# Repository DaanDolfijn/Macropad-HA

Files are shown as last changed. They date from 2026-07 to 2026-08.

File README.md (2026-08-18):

# Macropad-HA
<h2>A macropad that controls home assistant using espHome.</h2>
<p>This is NOT a Hackpad</p> 

<br>

<br>
<a href="https://youtu.be/JzanmzNsBhA"> See working here</a>
<h2>Features</h2>
<p>
  1. 4x4 buttons that are programmable in HA. <br>
  2. An 128X64 oled screen that displays time and whats playing on spotify using a HA spotify intergration. <br>
  3. 2 rgb leds that are programmable in HA. <br>
  4. 2 potentiometers that are programmable in HA</p>

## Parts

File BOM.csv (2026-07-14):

Item | Qty Needed | Qty Owned | Price ($)
Potentimetor | 2 | 2 | 3
RGB leds | 2 | 2 | 0.60
Oled screen 128x64 | 1 | 1 | 2
ESP32 s3 | 1 | 1 | 8
Keyboard switch | 16 | 16 | 3
Keycap | 16 | 16 | 5
PCB | 1 | 0 | 25

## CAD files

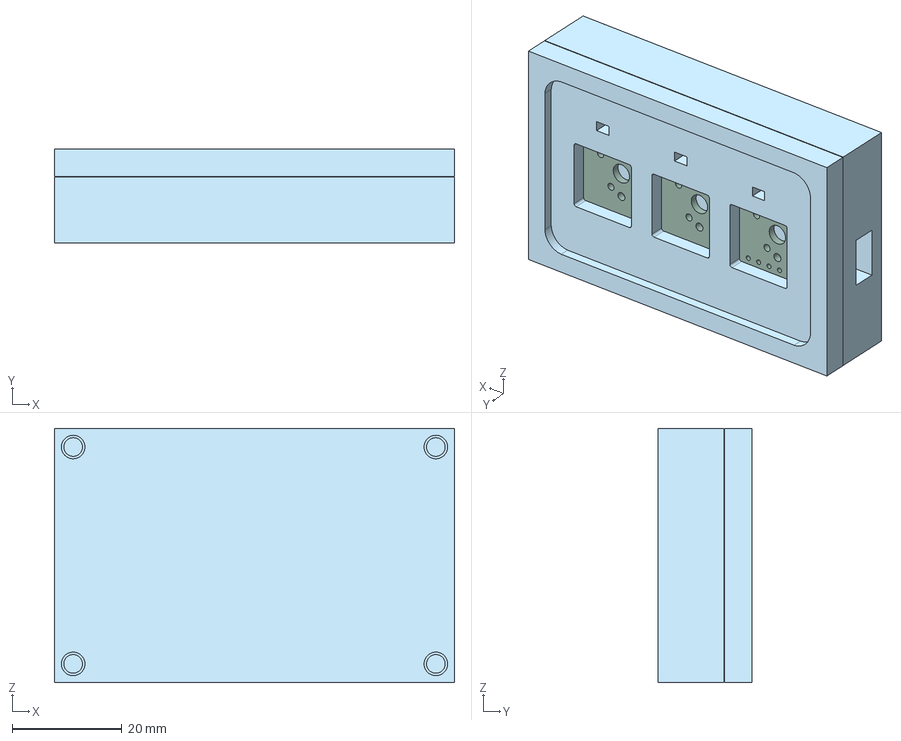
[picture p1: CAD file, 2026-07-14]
Assembly.step
73.0 x 17.1 x 46.4 mm
yo_PCB

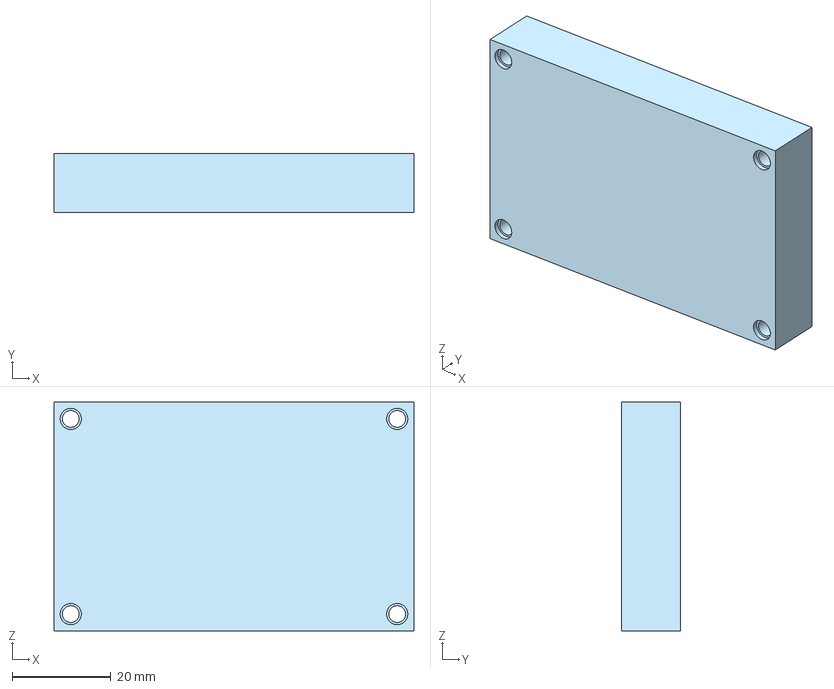
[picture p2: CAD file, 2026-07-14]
Bottom.step
73.0 x 12.0 x 46.4 mm

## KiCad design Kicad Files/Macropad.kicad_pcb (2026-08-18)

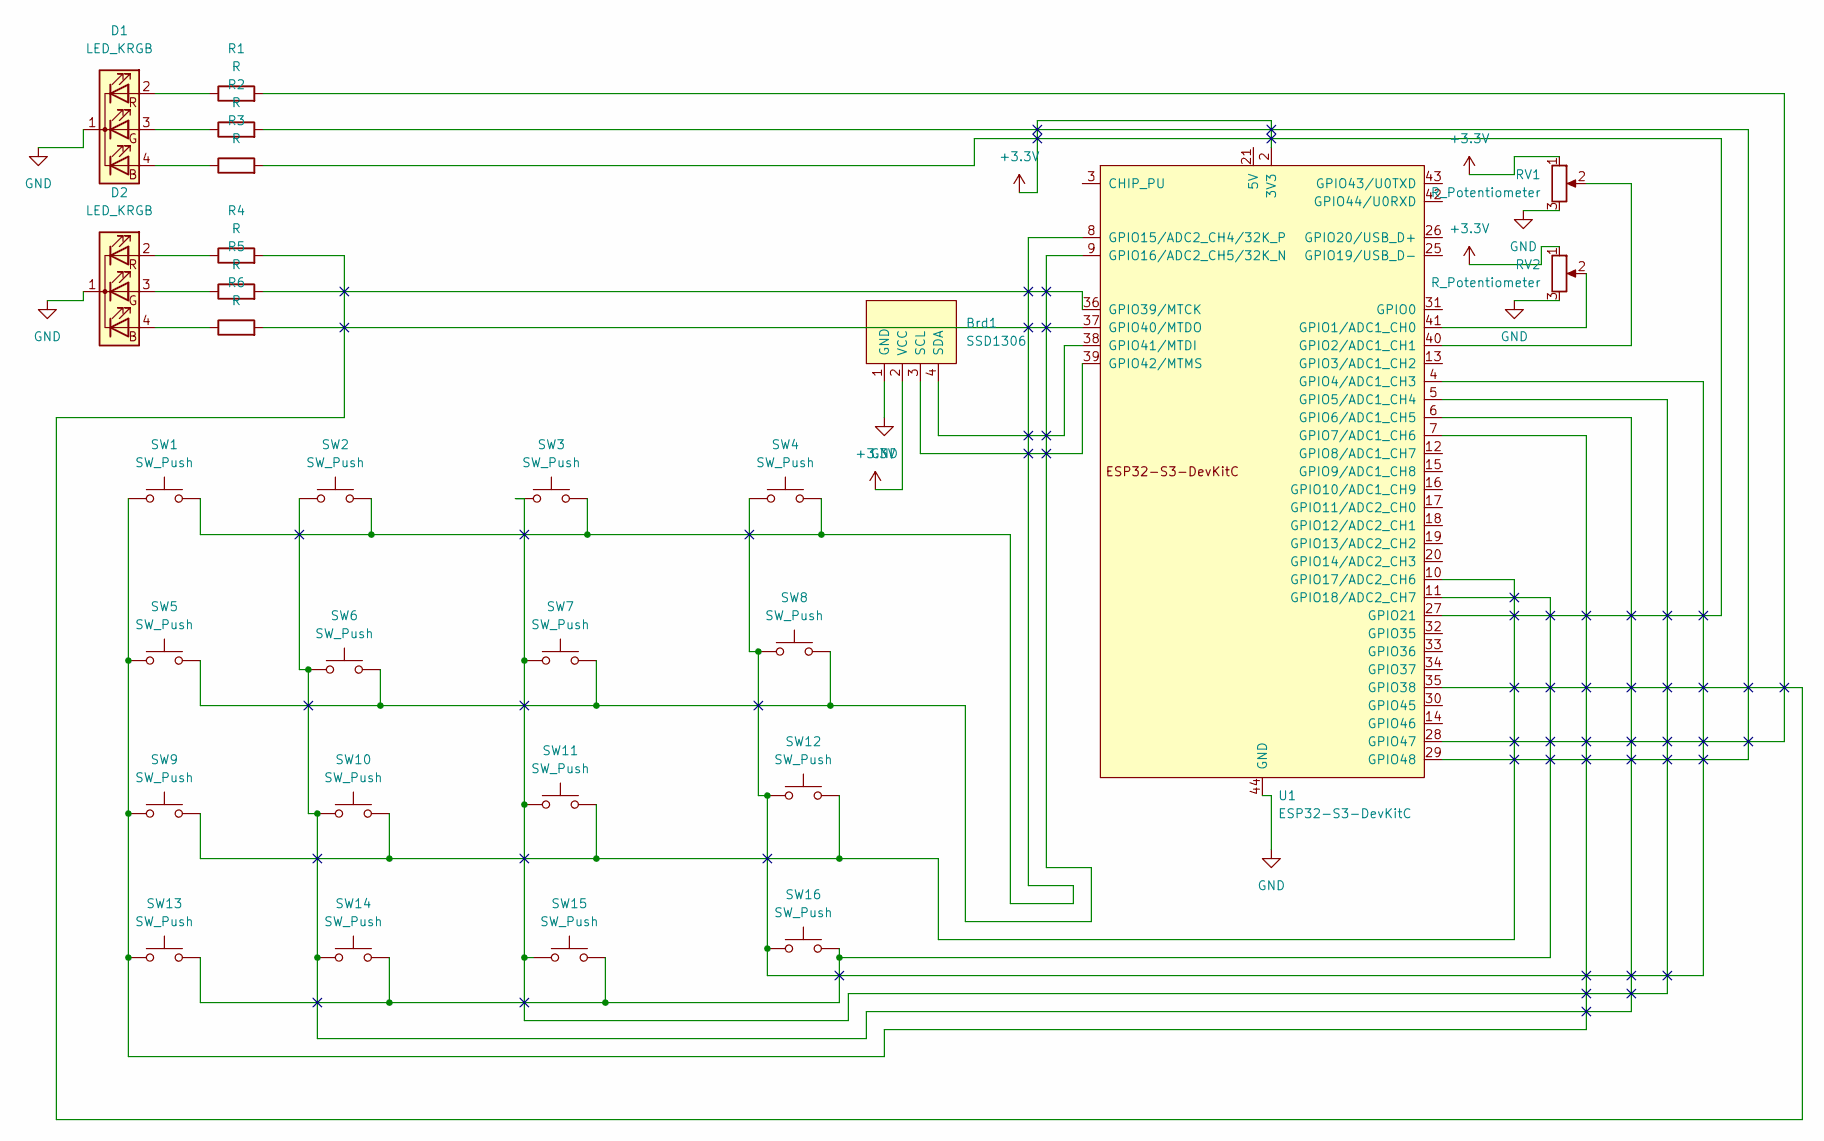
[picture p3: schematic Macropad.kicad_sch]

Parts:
Brd1: SSD1306; 128x64OLED
D1, D2: LED_KRGB; LED_D5.0mm-4_RGB_Staggered_Pins
R1, R2, R3, R4, R5, R6: R; R_Axial_DIN0207_L6.3mm_D2.5mm_P10.16mm_Horizontal
RV1, RV2: R_Potentiometer; TRIM_WH148-1A-2-18T-L20
SW1, SW2, SW3, SW4, SW5, SW6, SW7, SW8, SW9, SW10, SW11, SW12, SW13, SW14, SW15, SW16: SW_Push; SW_Cherry_MX_1.00u_PCB
U1: ESP32-S3-DevKitC

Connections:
+3.3V: Brd1.2 (VCC), RV1.1, RV2.1, U1.1 (3V3), U1.2 (3V3)
GND: Brd1.1 (GND), D1.1 (K), D2.1 (K), RV1.3, RV2.3, U1.22 (GND), U1.23 (GND), U1.24 (GND), U1.44 (GND)
unnamed: Brd1.3 (SCL), U1.39 (GPIO42/MTMS)
unnamed: Brd1.4 (SDA), U1.38 (GPIO41/MTDI)
unnamed: D1.4 (BA), R3.1
unnamed: D1.3 (GA), R2.1
unnamed: D1.2 (RA), R1.1
unnamed: D2.4 (BA), R6.1
unnamed: D2.3 (GA), R5.1
unnamed: D2.2 (RA), R4.1
unnamed: RV2.2, U1.41 (GPIO1/ADC1_CH0)
unnamed: RV1.2, U1.40 (GPIO2/ADC1_CH1)
unnamed: SW4.1, SW8.1, SW12.1, SW16.1, U1.4 (GPIO4/ADC1_CH3)
unnamed: SW3.1, SW7.1, SW11.1, SW15.1, U1.5 (GPIO5/ADC1_CH4)
unnamed: SW2.1, SW6.1, SW10.1, SW14.1, U1.6 (GPIO6/ADC1_CH5)
unnamed: SW1.1, SW5.1, SW9.1, SW13.1, U1.7 (GPIO7/ADC1_CH6)
unnamed: SW1.2, SW2.2, SW3.2, SW4.2, U1.8 (GPIO15/ADC2_CH4/32K_P)
unnamed: SW5.2, SW6.2, SW7.2, SW8.2, U1.9 (GPIO16/ADC2_CH5/32K_N)
unnamed: SW9.2, SW10.2, SW11.2, SW12.2, U1.10 (GPIO17/ADC2_CH6)
unnamed: SW13.2, SW14.2, SW15.2, SW16.2, U1.11 (GPIO18/ADC2_CH7)
unnamed: R3.2, U1.27 (GPIO21)
unnamed: R4.2, U1.35 (GPIO38)
unnamed: R5.2, U1.36 (GPIO39/MTCK)
unnamed: R6.2, U1.37 (GPIO40/MTDO)
unnamed: R1.2, U1.28 (GPIO47)
unnamed: R2.2, U1.29 (GPIO48)

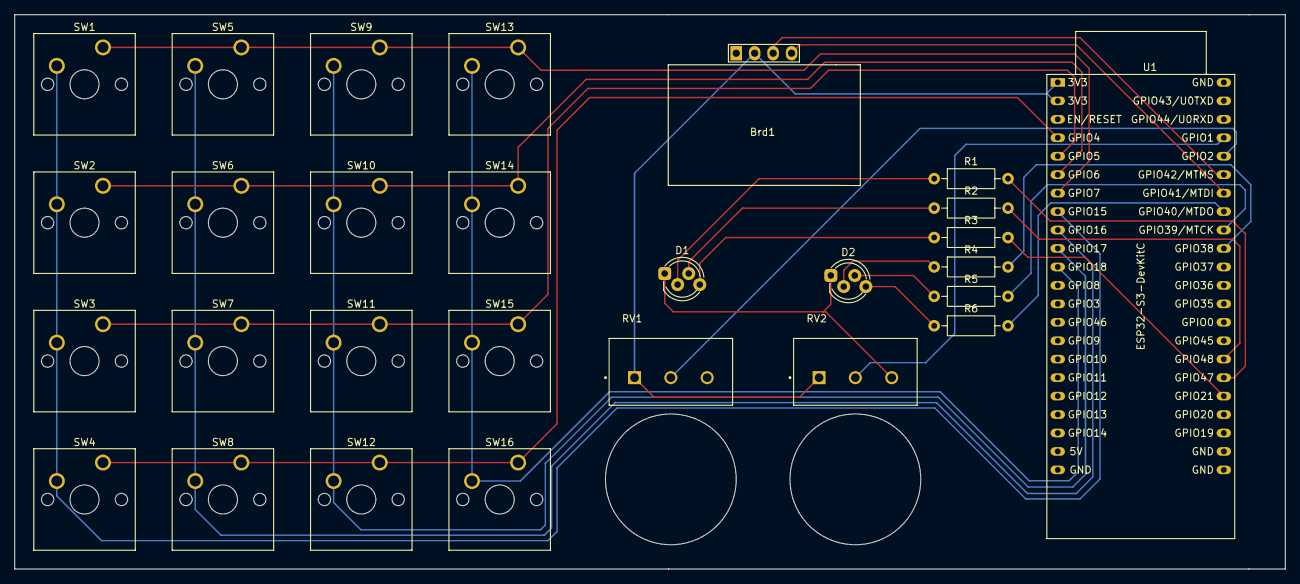
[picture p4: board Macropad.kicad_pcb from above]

Board: 2 copper layers, 174.9 x 76.3 mm, 28 parts (0 on the bottom side), 26 nets.

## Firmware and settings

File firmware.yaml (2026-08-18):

esphome:
  name: my-esp32 

esp32:
  board: esp32-s3-devkitc-1
  framework:
    type: esp-idf
  variant: esp32s3

wifi:
  ssid: "SSID"
  password: "PASSWORD"

logger:
api:
ota:
  - platform: esphome
    password: "PASSWORD"

i2c:
  sda: GPIO41
  scl: GPIO42
  scan: true
  id: bus_a

time:
  - platform: homeassistant
    id: ha_time

sensor:
  - platform: adc
    pin: GPIO1
    name: "Potmeter 1"
    id: pot1
    update_interval: 200ms
    attenuation: 12db
    unit_of_measurement: "%"
    filters:
      - sliding_window_moving_average:
          window_size: 5
          send_every: 1
      - calibrate_linear:
          datapoints:
            - 0.0 -> 0.0
            - 3.13 -> 100.0
      - clamp:
          min_value: 0
          max_value: 100
          ignore_out_of_range: false
      - round: 0
      - delta: 2
  - platform: adc
    pin: GPIO2
    name: "Potmeter 2"
    id: pot2
    update_interval: 200ms
    attenuation: 12db
    unit_of_measurement: "%"
    filters:
      - sliding_window_moving_average:
          window_size: "5"
          send_every: "1"
      - calibrate_linear:
          datapoints:
            - 0.0 -> 0.00
            - 3.13 -> 100.0
      - clamp:
          min_value: "0"
          max_value: "100"
          ignore_out_of_range: false
      - round: 0
      - delta: 2
text_sensor:
  - platform: homeassistant
    id: spotify_title
    entity_id: media_player.spotify_daniel
    attribute: media_title
  - platform: homeassistant
    id: spotify_artist
    entity_id: media_player.spotify_daniel
    attribute: media_artist

matrix_keypad:
  rows:
    - pin: GPIO4
    - pin: GPIO5
    - pin: GPIO6
    - pin: GPIO7
  columns:
    - pin:
        number: GPIO15
        mode:
          input: true
          pullup: true
    - pin:
        number: GPIO16
        mode:
          input: true
          pullup: true
    - pin:
        number: GPIO17
        mode:
          input: true
          pullup: true
    - pin:
        number: GPIO18
        mode:
          input: true
          pullup: true

  keys: 12345678abcdefgh
binary_sensor:
  - platform: matrix_keypad
    name: "Knop 1"
    key: '1'
  - platform: matrix_keypad
    name: "Knop 2"
    key: '2'
  - platform: matrix_keypad
    name: "Knop 3"
    key: '3'
  - platform: matrix_keypad
    name: "Knop 4"
    key: '4'
  - platform: matrix_keypad
    name: "Knop 5"
    key: '5'
  - platform: matrix_keypad
    name: "Knop 6"
    key: '6'
  - platform: matrix_keypad
    name: "Knop 7"
    key: '7'
  - platform: matrix_keypad
    name: "Knop 8"
    key: '8'
  - platform: matrix_keypad
    name: "Knop 9"
    key: 'a'
  - platform: matrix_keypad
    name: "Knop 10"
    key: 'b'
  - platform: matrix_keypad
    name: "Knop 11"
    key: 'c'
  - platform: matrix_keypad
    name: "Knop 12"
    key: 'd'
  - platform: matrix_keypad
    name: "Knop 13"
    key: 'e'
  - platform: matrix_keypad
    name: "Knop 14"
    key: 'f'
  - platform: matrix_keypad
    name: "Knop 15"
    key: 'g'
  - platform: matrix_keypad
    name: "Knop 16"
    key: 'h'

output:
  - platform: ledc
    pin: GPIO47
    id: led1_red
  - platform: ledc
    pin: GPIO48
    id: led1_green
  - platform: ledc
    pin: GPIO21
    id: led1_blue
    
  - platform: ledc
    pin: GPIO38
    id: led2_red
  - platform: ledc
    pin: GPIO39
    id: led2_green
  - platform: ledc
    pin: GPIO40
    id: led2_blue

light:
  - platform: rgb
    name: "RGB LED 1"
    red: led1_red
    green: led1_green
    blue: led1_blue
  - platform: rgb
    name: "RGB LED 2"
    red: led2_red
    green: led2_green
    blue: led2_blue

font:
  - file: "gfonts://Courier+Prime"
    id: Courier_Prime_10
    size: 10
  - file: "gfonts://Courier+Prime"
    id: Courier_Prime_14
    size: 14
  - file: "gfonts://Courier+Prime"
    id: Courier_Prime_8
    size: 8

display:
  - platform: ssd1306_i2c
    model: SSD1306_128X64
    address: 0x3c
    id: my_display
    update_interval: 1s
    lambda: |-
      //time
      auto time = id(ha_time).now();
      if (time.is_valid()) {
        it.strftime(40, 23, id(Courier_Prime_14), Color(255, 255, 255), "%H:%M", time);
      }

      // Playing + songname
      it.print(4, 44, id(Courier_Prime_10), Color(255, 255, 255), "playing:");
      it.print(54, 44, id(Courier_Prime_10), Color(255, 255, 255), id(spotify_title).state.c_str());

      // By + artiest
      it.print(4, 53, id(Courier_Prime_8), Color(255, 255, 255), "By:");
      it.print(19, 53, id(Courier_Prime_8), Color(255, 255, 255), id(spotify_artist).state.c_str());

      // Line
      it.line(0, 19, 126, 19, Color(255, 255, 255));
      it.line(0, 39, 126, 39, Color(255, 255, 255));
